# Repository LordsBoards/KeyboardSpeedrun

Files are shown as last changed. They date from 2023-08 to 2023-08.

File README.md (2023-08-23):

# Speedrun 40% PCB Keyboard Design with KiCAD

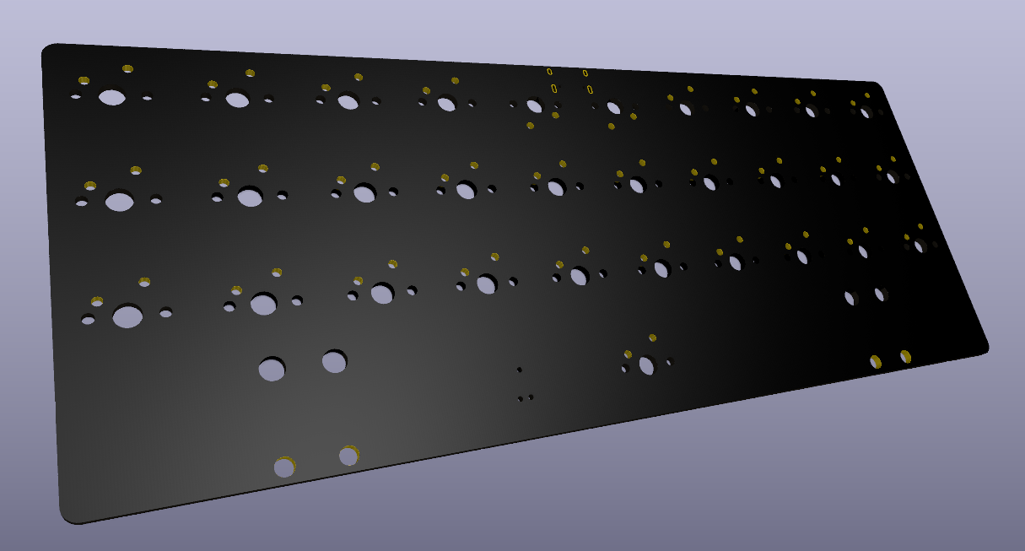
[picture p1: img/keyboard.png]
Keyboard


**Keyboard design is supposed to be hard, isn't it? No longer.**

## Features

- ARM microcontroller with 256k of flash, USB, and QMK/Vial support
- USB-C port with ESD protection
- 4-layer board design
- 6 pin tag connect port for SWD programming
- Easy and quick routing

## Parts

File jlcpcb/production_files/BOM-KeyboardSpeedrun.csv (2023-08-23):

Comment | Designator | Footprint | LCSC
STM32L443CCUx | U1 | QFN-48-1EP_7x7mm_P0.5mm_EP5.6x5.6mm_ThermalVias | C1338637
100R @ 100 MHz | FB1 | L_0603_1608Metric | C14709
1u | C1,C2 | C_0402_1005Metric | C15684
USB_C_Receptacle_USB2.0 | J1 | USB_C_Receptacle_HRO_TYPE-C-31-M-12 | C165948
100n | C4,C5,C6,C7 | C_0402_1005Metric | C169292
500mA | F1 | Fuse_0805_2012Metric | C2833485
5.1k | R1,R2 | R_0402_1005Metric | C2906948
SW_Push | SW1,SW2 | SW_SPST_SKQG_WithStem | C318884
AP2127N-3.3 | U3 | SOT-23 | C347222
4.7u | C3 | C_0402_1005Metric | C368809
10k | R3 | R_0402_1005Metric | C60490
USBLC6-2SC6 | U2 | SOT-23-6 | C7519
D_Small | D1,D10,D11,D12,D13,D14,D15,D16,D17,D18,D19,D2,D20,D21,D22,D23,D24,D25,D26,D27,D28,D29,D3,D30,D31,D4,D5,D6,D7,D8,D9 | D_SOD-123 | C81598

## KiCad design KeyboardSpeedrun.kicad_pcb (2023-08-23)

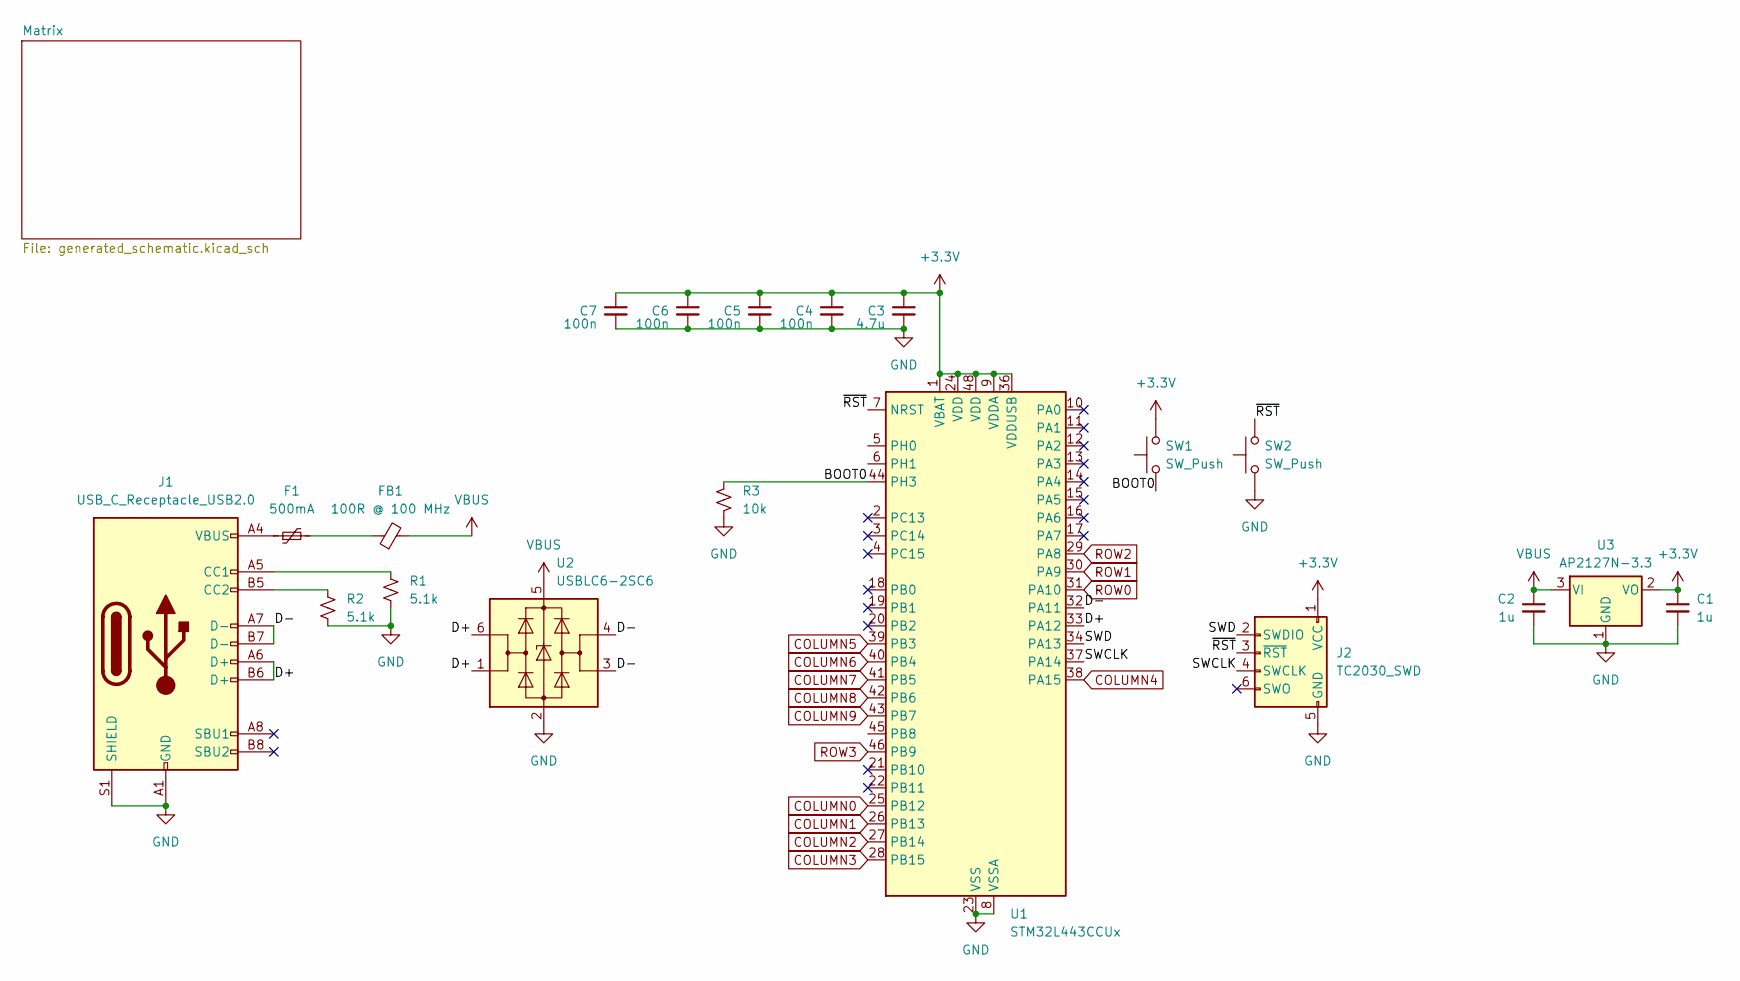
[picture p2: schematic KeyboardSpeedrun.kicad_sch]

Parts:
C1, C2: 1u; C_0402_1005Metric; LCSC C15684
C3: 4.7u; C_0402_1005Metric; LCSC C368809
C4, C5, C6, C7: 100n; C_0402_1005Metric; LCSC C169292
F1: 500mA; Fuse_0805_2012Metric; LCSC C2833485
FB1: 100R @ 100 MHz; L_0603_1608Metric; LCSC C14709
J1: USB_C_Receptacle_USB2.0; USB_C_Receptacle_HRO_TYPE-C-31-M-12; LCSC C165948
J2: TC2030_SWD; CON_TC2030_outlined
R1, R2: 5.1k; R_0402_1005Metric; LCSC C2906948
R3: 10k; R_0402_1005Metric; LCSC C60490
SW1, SW2: SW_Push; SW_SPST_SKQG_WithStem; LCSC C318884
U1: STM32L443CCUx; QFN-48-1EP_7x7mm_P0.5mm_EP5.6x5.6mm_ThermalVias; LCSC C1338637
U2: USBLC6-2SC6; SOT-23-6; LCSC C7519
U3: AP2127N-3.3; SOT-23; LCSC C347222

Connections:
+3.3V: C1.1, C3.1, C4.1, C5.1, C6.1, C7.1, J2.1 (VCC), SW1.2, U1.1 (VBAT), U1.9 (VDDA), U1.24 (VDD), U1.36 (VDDUSB), U1.48 (VDD), U3.2 (VO)
/BOOT0: R3.1, SW1.1, U1.44 (PH3)
/D+: J1.A6 (D+), J1.B6 (D+), U1.33 (PA12), U2.1 (I/O1), U2.6 (I/O1)
/D-: J1.A7 (D-), J1.B7 (D-), U1.32 (PA11), U2.3 (I/O2), U2.4 (I/O2)
/SWCLK: J2.4 (SWCLK), U1.37 (PA14)
/SWD: J2.2 (SWDIO), U1.34 (PA13)
/~RST: J2.3 (~RST), SW2.2, U1.7 (NRST)
COLUMN0: U1.25 (PB12); also elsewhere on the board
COLUMN1: U1.26 (PB13); also elsewhere on the board
COLUMN2: U1.27 (PB14); also elsewhere on the board
COLUMN3: U1.28 (PB15); also elsewhere on the board
COLUMN4: U1.38 (PA15); also elsewhere on the board
COLUMN5: U1.39 (PB3); also elsewhere on the board
COLUMN6: U1.40 (PB4); also elsewhere on the board
COLUMN7: U1.41 (PB5); also elsewhere on the board
COLUMN8: U1.42 (PB6); also elsewhere on the board
COLUMN9: U1.43 (PB7); also elsewhere on the board
GND: C1.2, C2.2, C3.2, C4.2, C5.2, C6.2, C7.2, J1.A1 (GND), J1.A12 (GND), J1.B1 (GND), J1.B12 (GND), J1.S1 (SHIELD), J2.5 (GND), R1.2, R2.2, R3.2, SW2.1, U1.8 (VSSA), U1.23 (VSS), U1.35 (VSS), U1.47 (VSS), U1.49 (VSS), U2.2 (GND), U3.1 (GND)
unnamed: F1.1, J1.A4 (VBUS), J1.A9 (VBUS), J1.B4 (VBUS), J1.B9 (VBUS)
unnamed: F1.2, FB1.1
unnamed: J1.A5 (CC1), R1.1
unnamed: J1.B5 (CC2), R2.1
ROW0: U1.31 (PA10); also elsewhere on the board
ROW1: U1.30 (PA9); also elsewhere on the board
ROW2: U1.29 (PA8); also elsewhere on the board
ROW3: U1.46 (PB9); also elsewhere on the board
VBUS: C2.1, FB1.2, U2.5 (VBUS), U3.3 (VI)

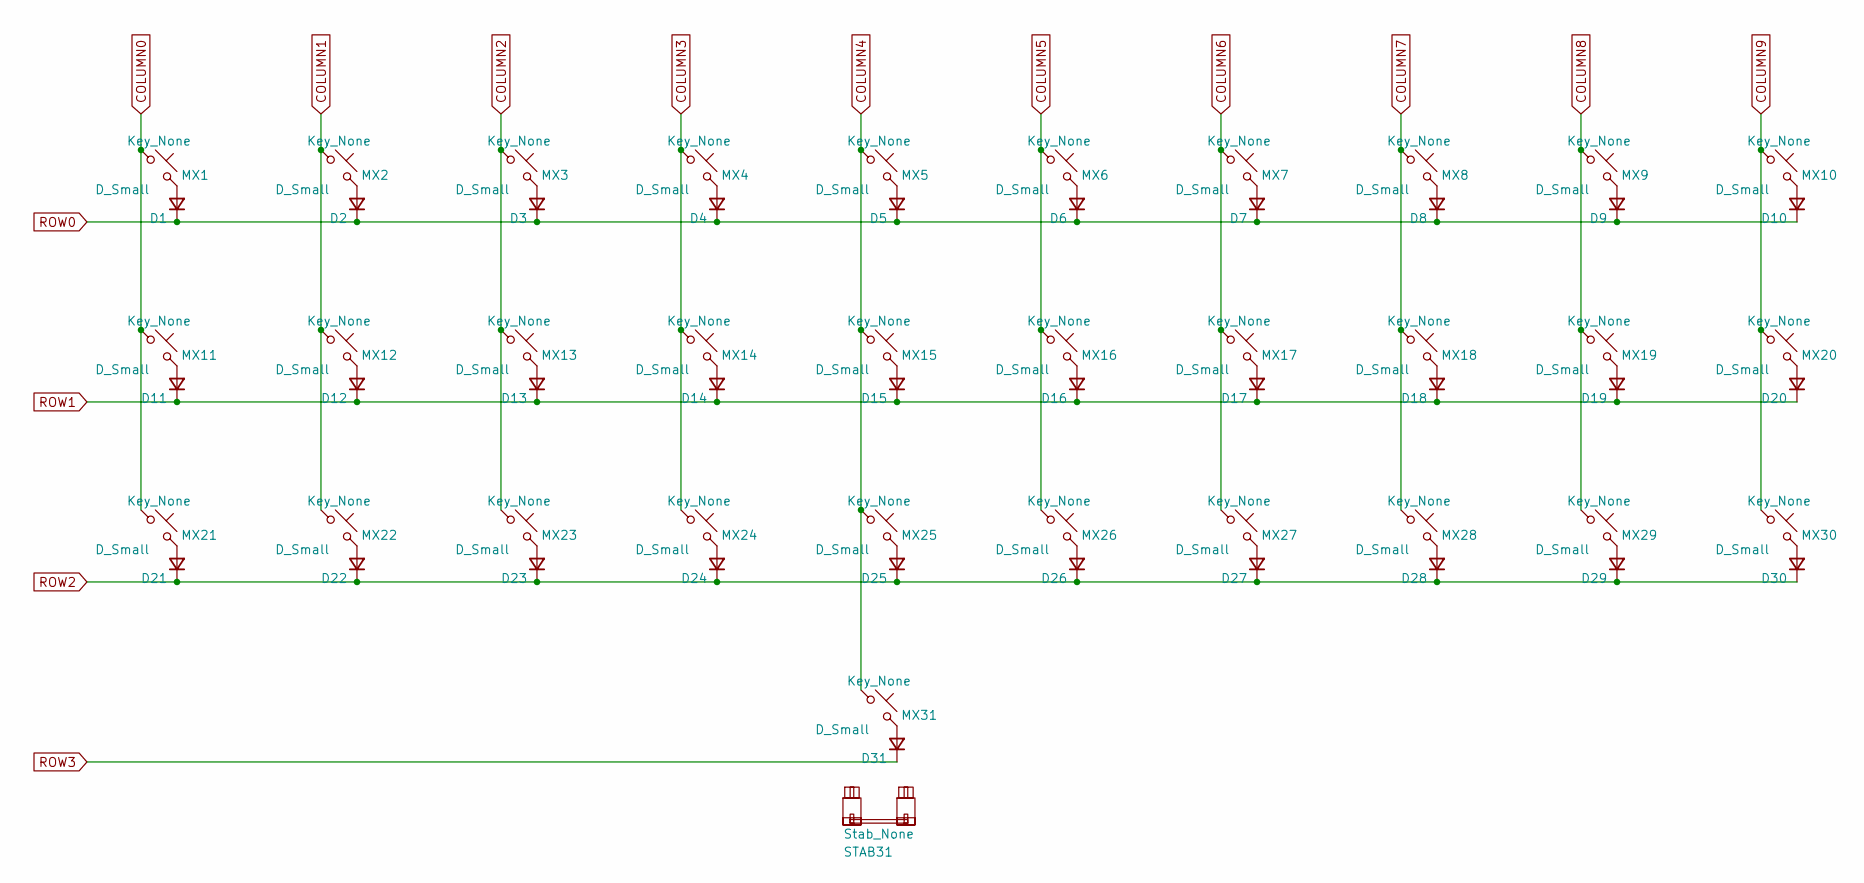
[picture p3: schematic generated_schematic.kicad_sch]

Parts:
D1, D2, D3, D4, D5, D6, D7, D8, D9, D10, D11, D12, D13, D14, D15, D16, D17, D18, D19, D20, D21, D22, D23, D24, D25, D26, D27, D28, D29, D30, D31: D_Small; D_SOD-123; LCSC C81598
MX1, MX2, MX3, MX4, MX5, MX6, MX7, MX8, MX9, MX10, MX11, MX12, MX13, MX14, MX15, MX16, MX17, MX18, MX19, MX20, MX21, MX22, MX23, MX24, MX25, MX26, MX27, MX28, MX29, MX30, MX31: Key_None; SW_MX_1u
STAB31: Stab_None; STAB_MX_P_10u

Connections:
COLUMN0: MX1.1, MX11.1, MX21.1; also elsewhere on the board
COLUMN1: MX2.1, MX12.1, MX22.1; also elsewhere on the board
COLUMN2: MX3.1, MX13.1, MX23.1; also elsewhere on the board
COLUMN3: MX4.1, MX14.1, MX24.1; also elsewhere on the board
COLUMN4: MX5.1, MX15.1, MX25.1, MX31.1; also elsewhere on the board
COLUMN5: MX6.1, MX16.1, MX26.1; also elsewhere on the board
COLUMN6: MX7.1, MX17.1, MX27.1; also elsewhere on the board
COLUMN7: MX8.1, MX18.1, MX28.1; also elsewhere on the board
COLUMN8: MX9.1, MX19.1, MX29.1; also elsewhere on the board
COLUMN9: MX10.1, MX20.1, MX30.1; also elsewhere on the board
unnamed: D1.2 (A), MX1.2
unnamed: D2.2 (A), MX2.2
unnamed: D3.2 (A), MX3.2
unnamed: D4.2 (A), MX4.2
unnamed: D5.2 (A), MX5.2
unnamed: D6.2 (A), MX6.2
unnamed: D7.2 (A), MX7.2
unnamed: D8.2 (A), MX8.2
unnamed: D9.2 (A), MX9.2
unnamed: D10.2 (A), MX10.2
unnamed: D11.2 (A), MX11.2
unnamed: D12.2 (A), MX12.2
unnamed: D13.2 (A), MX13.2
unnamed: D14.2 (A), MX14.2
unnamed: D15.2 (A), MX15.2
unnamed: D16.2 (A), MX16.2
unnamed: D17.2 (A), MX17.2
unnamed: D18.2 (A), MX18.2
unnamed: D19.2 (A), MX19.2
unnamed: D20.2 (A), MX20.2
unnamed: D21.2 (A), MX21.2
unnamed: D22.2 (A), MX22.2
unnamed: D23.2 (A), MX23.2
unnamed: D24.2 (A), MX24.2
unnamed: D25.2 (A), MX25.2
unnamed: D26.2 (A), MX26.2
unnamed: D27.2 (A), MX27.2
unnamed: D28.2 (A), MX28.2
unnamed: D29.2 (A), MX29.2
unnamed: D30.2 (A), MX30.2
unnamed: D31.2 (A), MX31.2
ROW0: D1.1 (K), D2.1 (K), D3.1 (K), D4.1 (K), D5.1 (K), D6.1 (K), D7.1 (K), D8.1 (K), D9.1 (K), D10.1 (K); also elsewhere on the board
ROW1: D11.1 (K), D12.1 (K), D13.1 (K), D14.1 (K), D15.1 (K), D16.1 (K), D17.1 (K), D18.1 (K), D19.1 (K), D20.1 (K); also elsewhere on the board
ROW2: D21.1 (K), D22.1 (K), D23.1 (K), D24.1 (K), D25.1 (K), D26.1 (K), D27.1 (K), D28.1 (K), D29.1 (K), D30.1 (K); also elsewhere on the board
ROW3: D31.1 (K); also elsewhere on the board

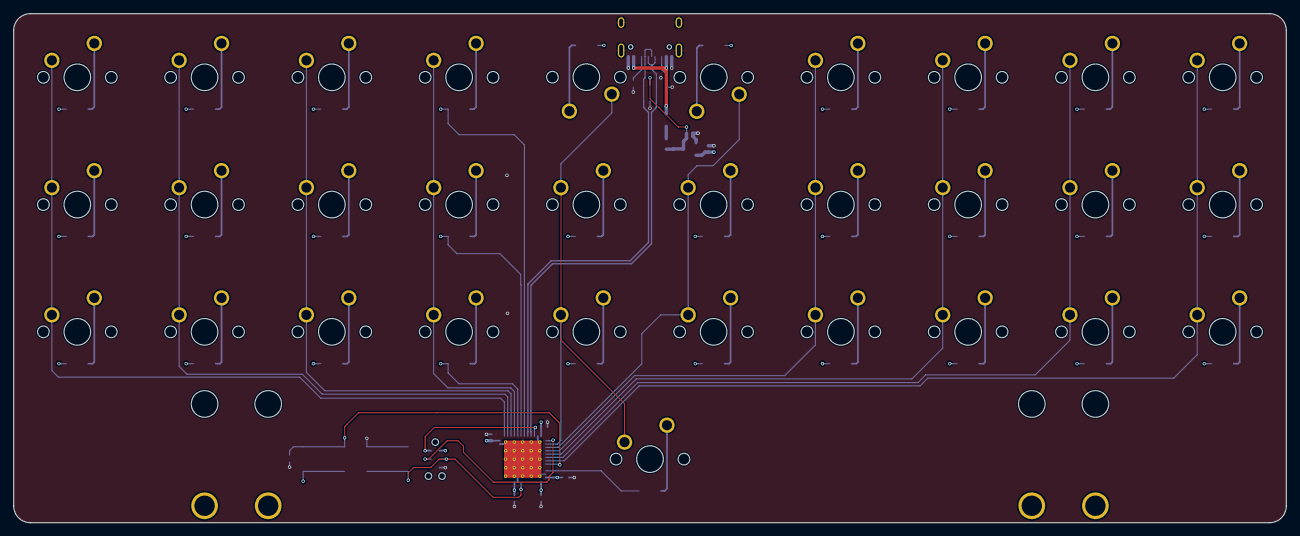
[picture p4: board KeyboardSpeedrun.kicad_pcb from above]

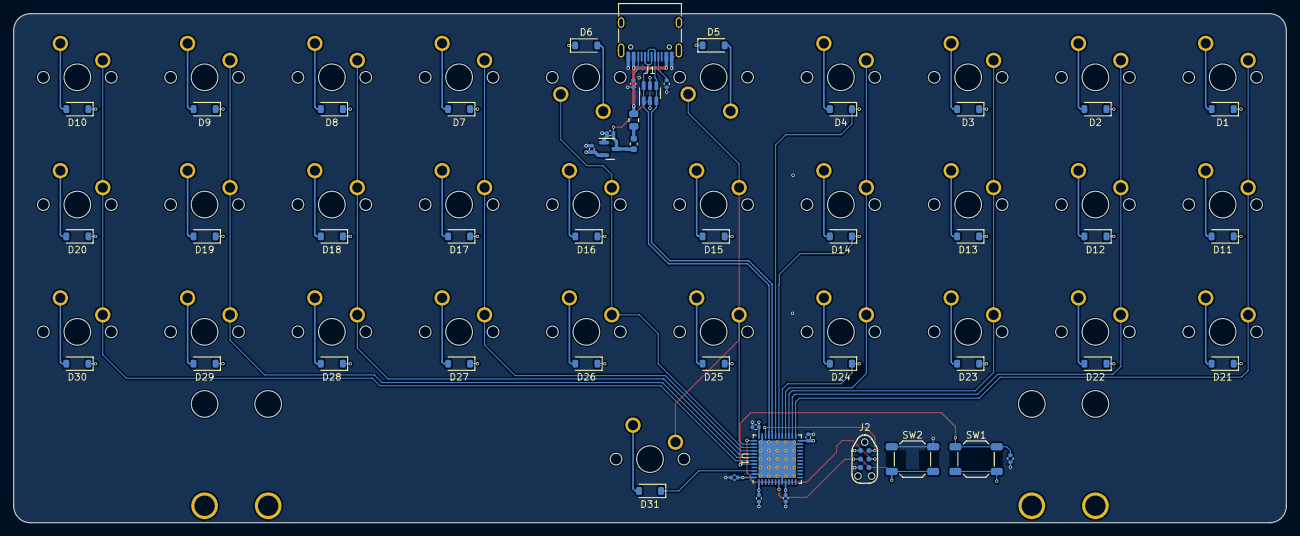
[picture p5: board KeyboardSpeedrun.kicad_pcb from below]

Board: 4 copper layers, 190.5 x 76.2 mm, 82 parts (50 on the bottom side), 58 nets.
